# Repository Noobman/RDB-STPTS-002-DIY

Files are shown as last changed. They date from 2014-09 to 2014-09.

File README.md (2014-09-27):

RDB-STPTS-002-DIY
=================

3Dprint or CNC extension board for *any* development board (5v or 3.3v logic level)

Further info at www.reprap.org/wiki/RDB-STPTS-002-DIY

Current TODO list:

*rework the 6.3mm fuse footprint (currently does not fit correctly)

*maybe? add led indicators for endstops driven by low Vg(th) mosfet

*maybe? add current limited vcc for endstops headers just in case

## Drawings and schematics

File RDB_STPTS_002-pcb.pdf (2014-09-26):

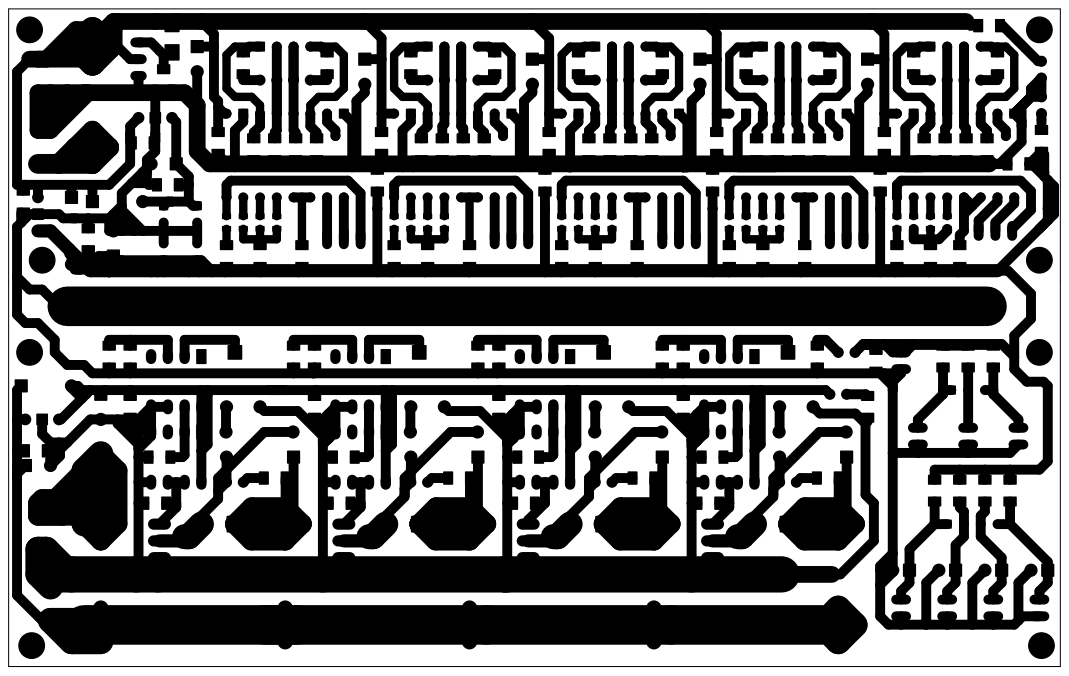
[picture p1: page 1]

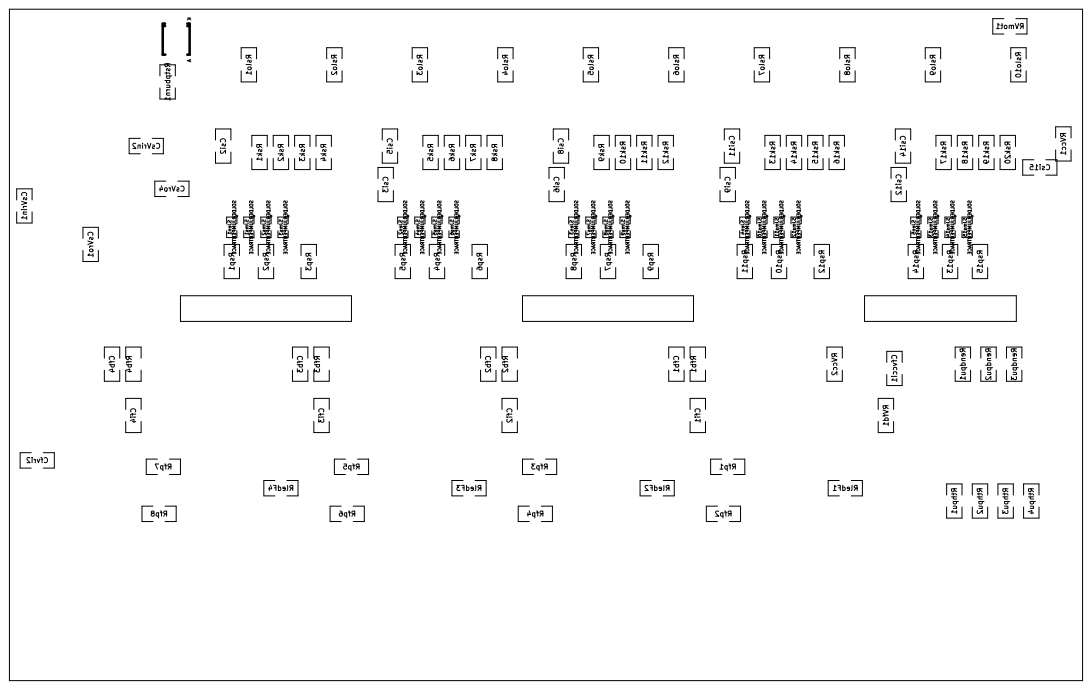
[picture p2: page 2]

SJen1 SOLDERJUMPERTRACE SJen2 SOLDERJUMPERTRACE SJen3 SOLDERJUMPERTRACE SJen4 SOLDERJUMPERTRACE SJen5 SOLDERJUMPERTRACE SJms1 SOLDERJUMPERTRACE SJms2 SOLDERJUMPERTRACE SJms3 SOLDERJUMPERTRACE SJms4 SOLDERJUMPERTRACE SJms5 SOLDERJUMPERTRACE SJms6 SOLDERJUMPERTRACE SJms7 SOLDERJUMPERTRACE SJms8 SOLDERJUMPERTRACE SJms9 SOLDERJUMPERTRACE SJms10 SOLDERJUMPERTRACE SJms11 SOLDERJUMPERTRACE SJms12 SOLDERJUMPERTRACE SJms13 SOLDERJUMPERTRACE SJms14 SOLDERJUMPERTRACE SJms15 SOLDERJUMPERTRACE RVcc1 RVmot1 CsVrin1 CsVro1 Cfi1 Csi2 Csi3 Csi5 Csi6 Csi8 Csi9 Csi11 Csi12 Csi14 Csi15 Rfp1 Rfp2 RledF1 Rsk1 Rsk2 Rsk3 Rsk4 Rsk5 Rsk6 Rsk7 Rsk8 Rsk9 Rsk10 Rsk11 Rsk12 Rsk13 Rsk14 Rsk15 Rsk16 Rsk17 Rsk18 Rsk19 Rsk20 Rslo1 Rslo2 Rslo3 Rslo4 Rslo5 Rslo6 Rslo7 Rslo8 Rslo9 Rslo10 Rsp1 Rsp2 Rsp3 Rsp5 Rsp4 Rsp6 Rsp8 Rsp7 Rsp9 Rsp10 Cfi2 Rfp3 Rfp4 RledF2 Cfi4 Cfi3 Rfp5 Rfp6 Rfp7 Rfp8 RledF4 RledF3 Cfvri2 Rfb4 Rfb3 Rfb2 Rfb1

# www.reprap.org/wiki/RDB - OSHW - GPLv3

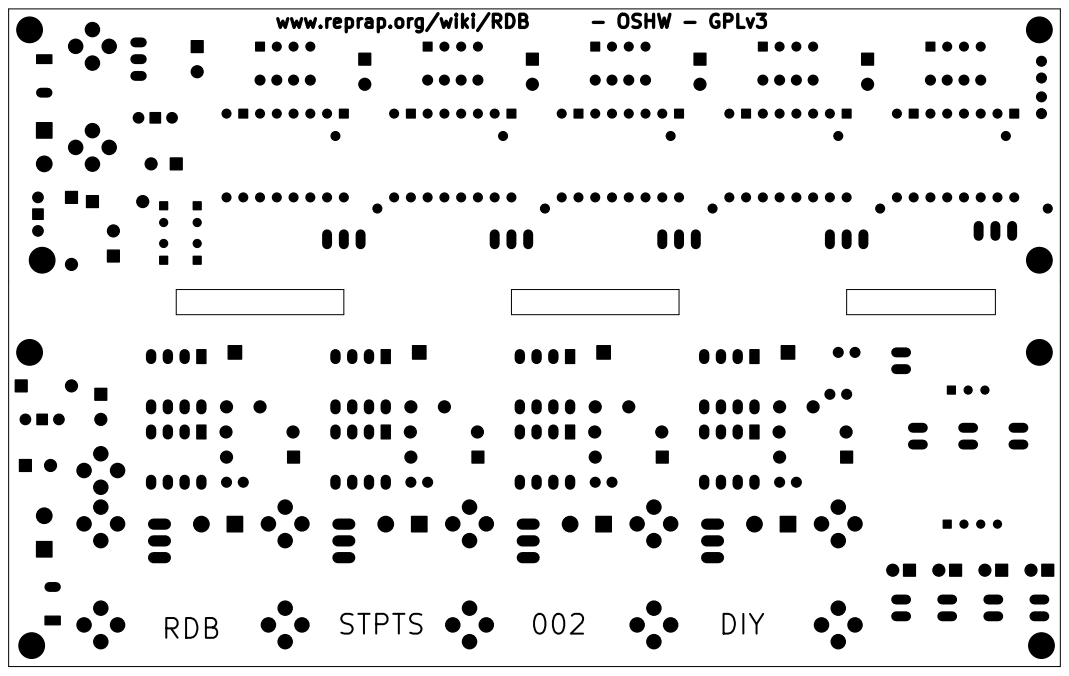
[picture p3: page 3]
RDB; STPTS; DIY

Pomot1 | Pomot2 | Pomot3 | Pomot4 | Pomot5 UP1 POLOLU_A4988 | UP2 POLOLU_A4988 | UP3 POLOLU_A4988 | UP4 POLOLU_A4988 | UP5 POLOLU_A4988 Rlim1 | Rlim2 | Rlim3 | Rlim4 | Rlim5 Hole1 Hole3 | Hole2 Hole4
Ledso1 BI_LED_2_PINS Ledso2 BI_LED_2_PINS | Ledso3 BI_LED_2_PINS Ledso4 BI_LED_2_PINS | Ledso5 BI_LED_2_PINS Ledso6 BI_LED_2_PINS | Ledso7 BI_LED_2_PINS Ledso8 BI_LED_2_PINS | Ledso9 BI_LED_2_PINS Ledso10 BI_LED_2_PINS Pc1 CONN_3 | Pc2 CONN_3 | Pc3 CONN_3 | Pc4 CONN_3 | Pc5 CONN_3 LedVcc1 | greenLedVmot1 green DFW1 FET_OUT1

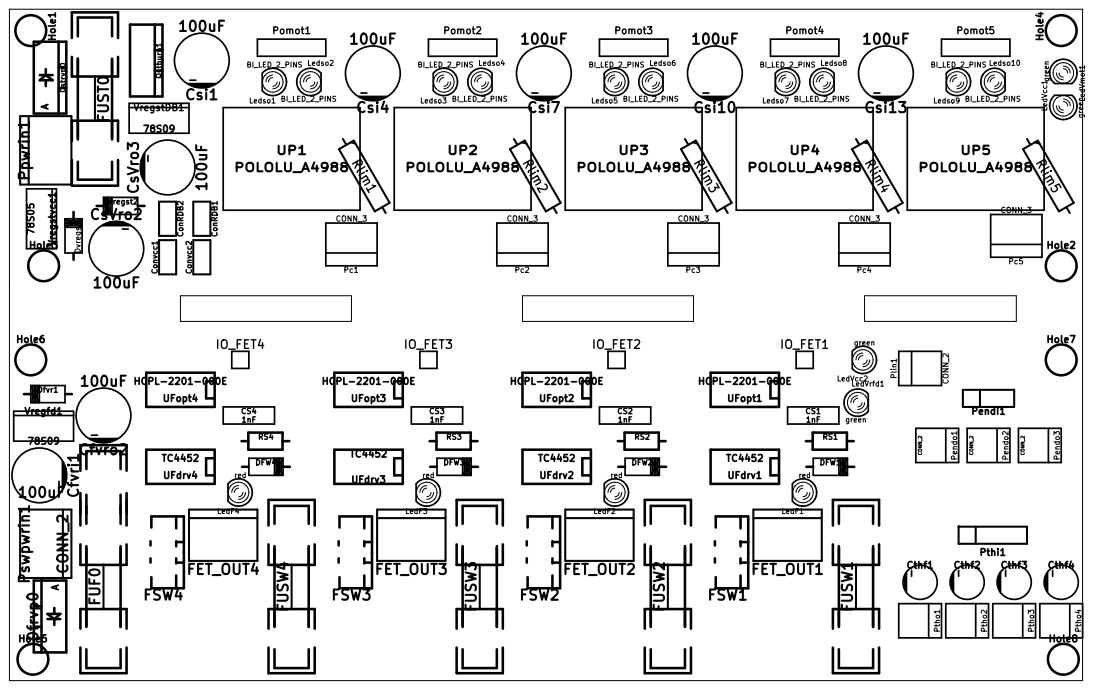
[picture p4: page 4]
FSW1; FUSW¹; LedF1 UFdrv1; red TC4452 DFW2 FET_OUT2; FSW2; FUSW²; LedF2; red Ppwrin1 Pswpwrin1; CONN_2; UFdrv2 TC4452 DFW4; DFW3 FET_OUT4; FET_OUT3; FSW4; FSW3 FUSW⁴; FUSW³; LedF3; red; LedF4; UFdrv3 TC4452 UFdrv4 TC4452 Dstrvp0 A; FUST0 Dfrvp0; Vregfd1; 78S09Vregstvcc1 78S⁰⁵; RS1 Hole5 Hole6; Hole7 Hole8 FUF0; ConRDB²; ConRDB¹ Convcc1; Convcc2 VregstDB1; 78S09 Dvregst2 Dvregst1; Qstburn1 Dfvr1; IO_FET4; IO_FET3; IO_FET2; IO_FET1; LedVrfd1 green; Pendo1 CONN_2; Pendo2 CONN_2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

UFopt1 HCPL-2201-000E UFopt2 HCPL-2201-000E UFopt3 HCPL-2201-000E UFopt4 HCPL-2201-000E

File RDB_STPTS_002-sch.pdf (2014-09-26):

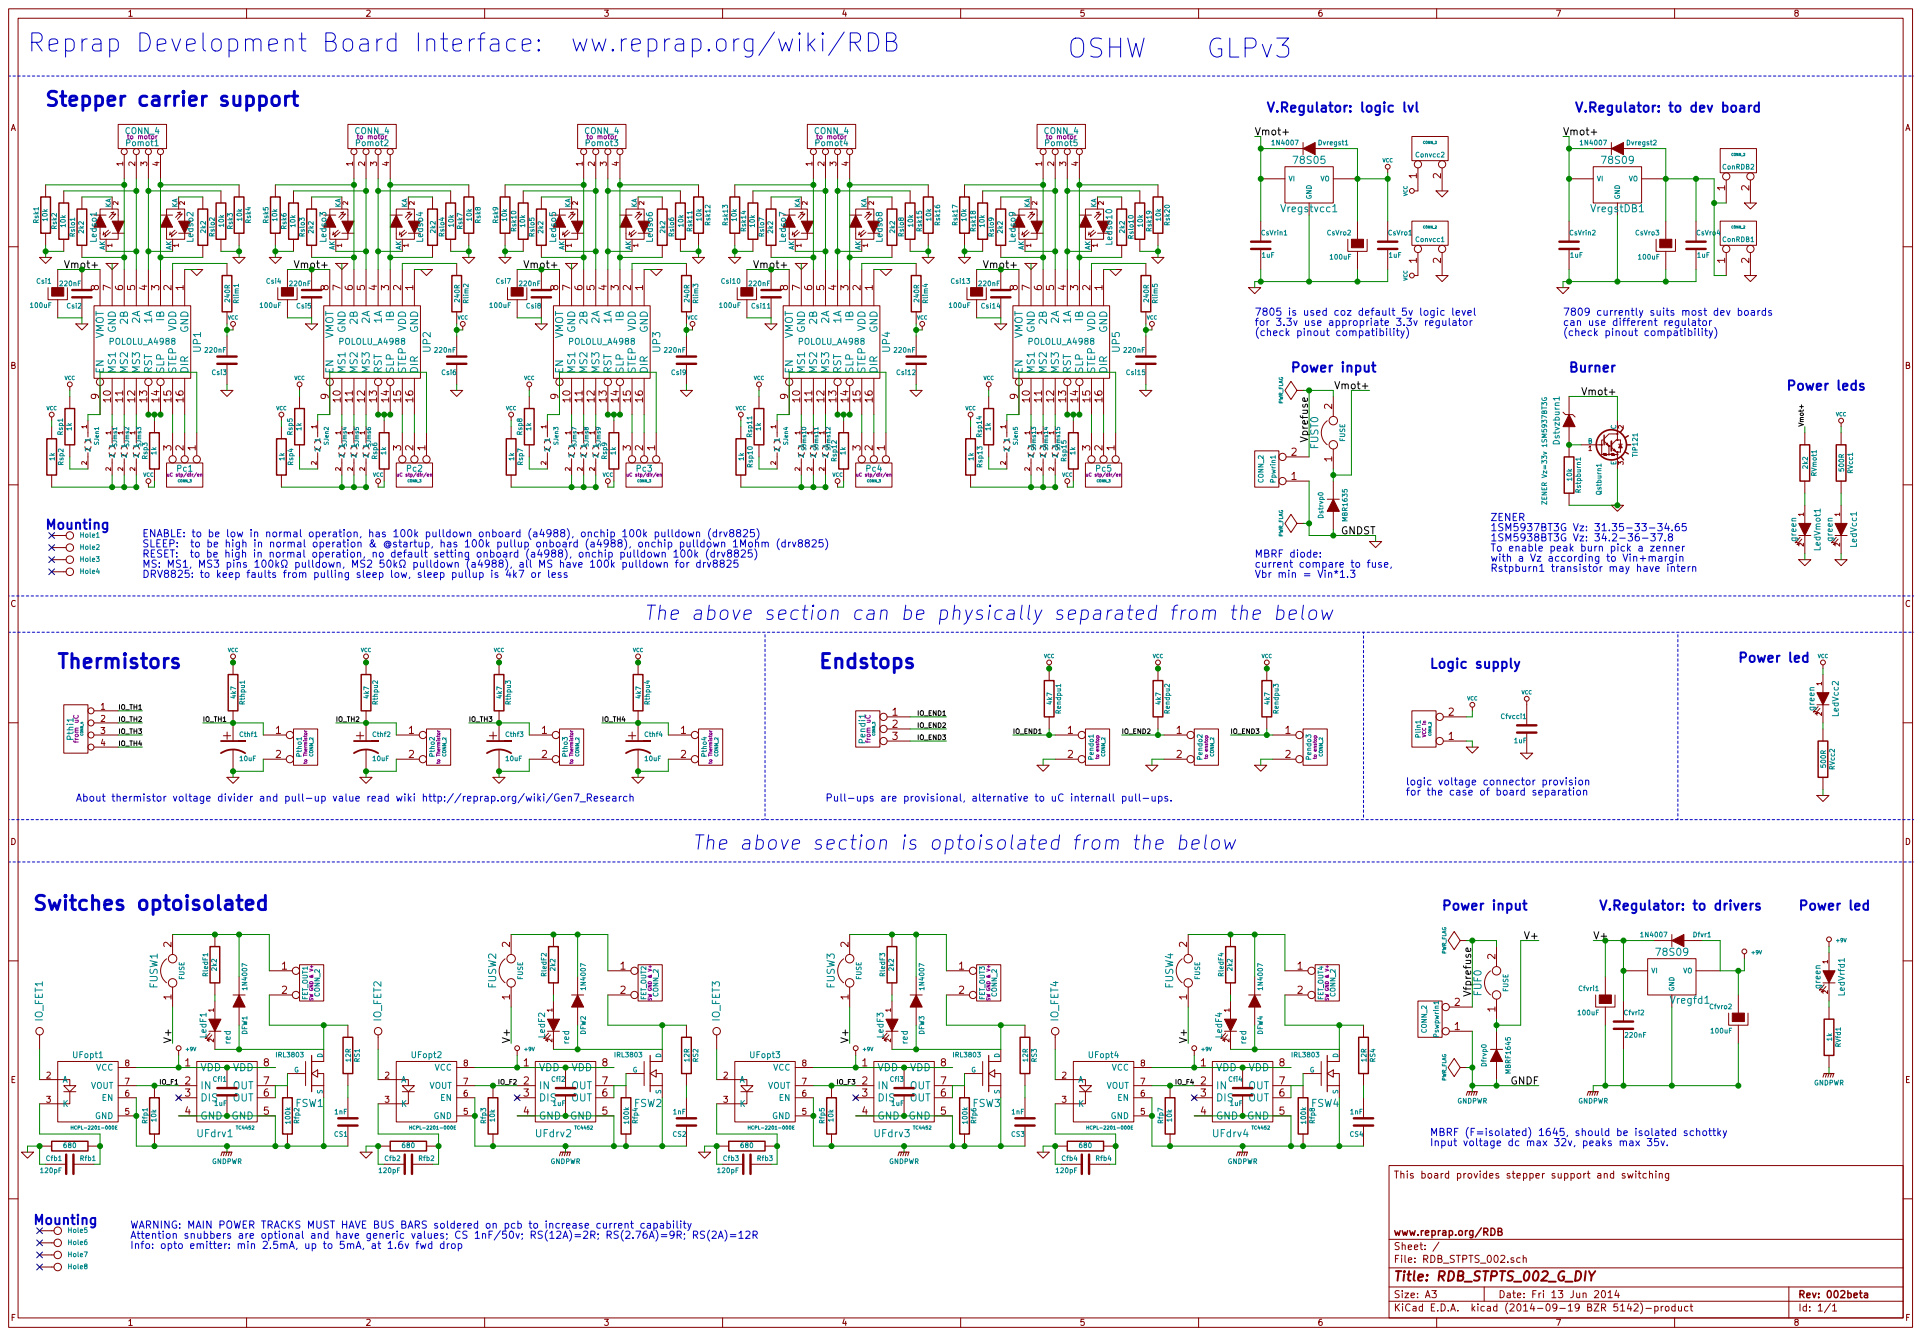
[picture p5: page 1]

CONN_2 V.Regulator: to dev board

1 VDD
(check pinout compatibility) MBRF diode: current compare to fuse, Vbr min = Vin*1.3 Vprefuse

VCC 7805 is used coz default 5v logic level
for 3.3v use appropriate 3.3v regulator

7809 currently suits most dev boards
can use different regulator
(check pinout compatibility)

9 MS1 10 MS2 11 MS3 12 RST 13 SLP 14 STEP 15 DIR 16 UP1POLOLU_A4988

9 MS1 10 MS2 11 MS3 12 RST 13 SLP 14 STEP 15 DIR 16 UP2POLOLU_A4988

9 MS1 10 MS2 11 MS3 12 RST 13 SLP 14 STEP 15 DIR 16 UP3POLOLU_A4988

9 MS1 10 MS2 11 MS3 12 RST 13 SLP 14 STEP 15 DIR 16 UP4POLOLU_A4988

9 MS1 10 MS2 11 MS3 12 RST 13 SLP 14 STEP 15 DIR 16 UP5POLOLU_A4988

3 Qstburn1 TIP121 Rstpburn1 10k Dstvzburn1 ZENER Vz=33v 1SM5937BT3G Vmot+ Burner ZENER

To enable peak burn pick a zenner
with a Vz according to Vin+margin
Rstpburn1 transistor may have intern

SLEEP: to be high in normal operation & @startup, has 100k pullup onboard (a4988), onchip pulldown 1Mohm (drv8825)
RESET: to be high in normal operation, no default setting onboard (a4988), onchip pulldown 100k (drv8825)
MS: MS1, MS3 pins 100k pulldown, MS2 50k pulldown (a4988), all MS have 100k pulldown for drv8825

The above section can be physically separated from the below

logic voltage connector provision
for the case of board separation

The above section is optoisolated from the below

HCPL-2201-000E Hole5 Hole6 Hole7 Hole8
Input voltage dc max 32v, peaks max 35v. Cfb1

MBRF (F=isolated) 1645, should be isolated schottky

This board provides stepper support and switching

WARNING: MAIN POWER TRACKS MUST HAVE BUS BARS soldered on pcb to increase current capability
Attention snubbers are optional and have generic values; CS 1nF/50v; RS(12A)=2R; RS(2.76A)=9R; RS(2A)=12R
Info: opto emitter: min 2.5mA, up to 5mA, at 1.6v fwd drop

File: RDB_STPTS_002.sch Sheet: / www.reprap.org/RDB

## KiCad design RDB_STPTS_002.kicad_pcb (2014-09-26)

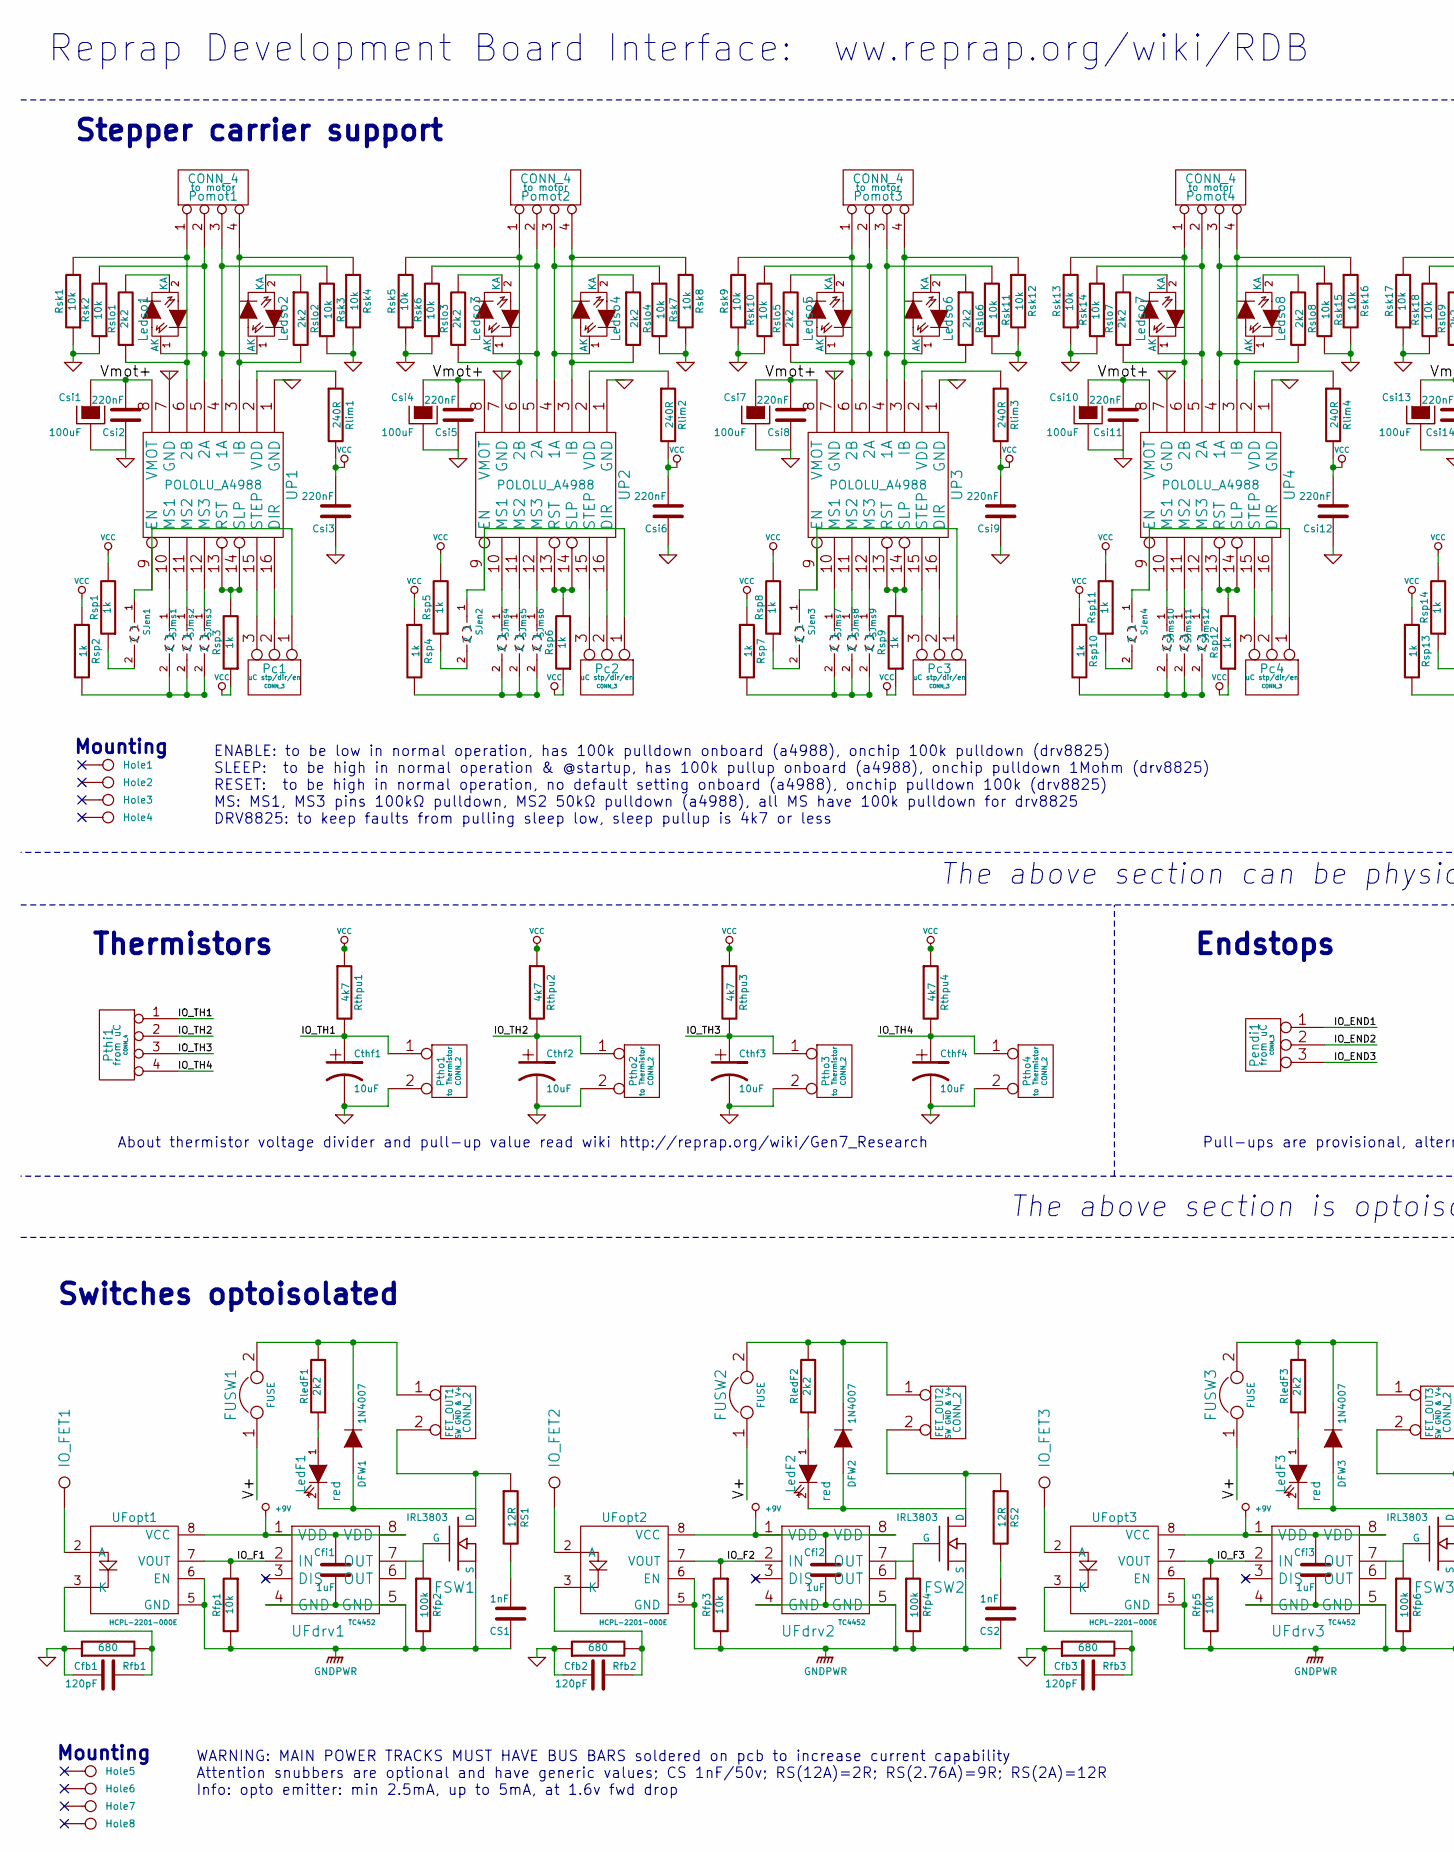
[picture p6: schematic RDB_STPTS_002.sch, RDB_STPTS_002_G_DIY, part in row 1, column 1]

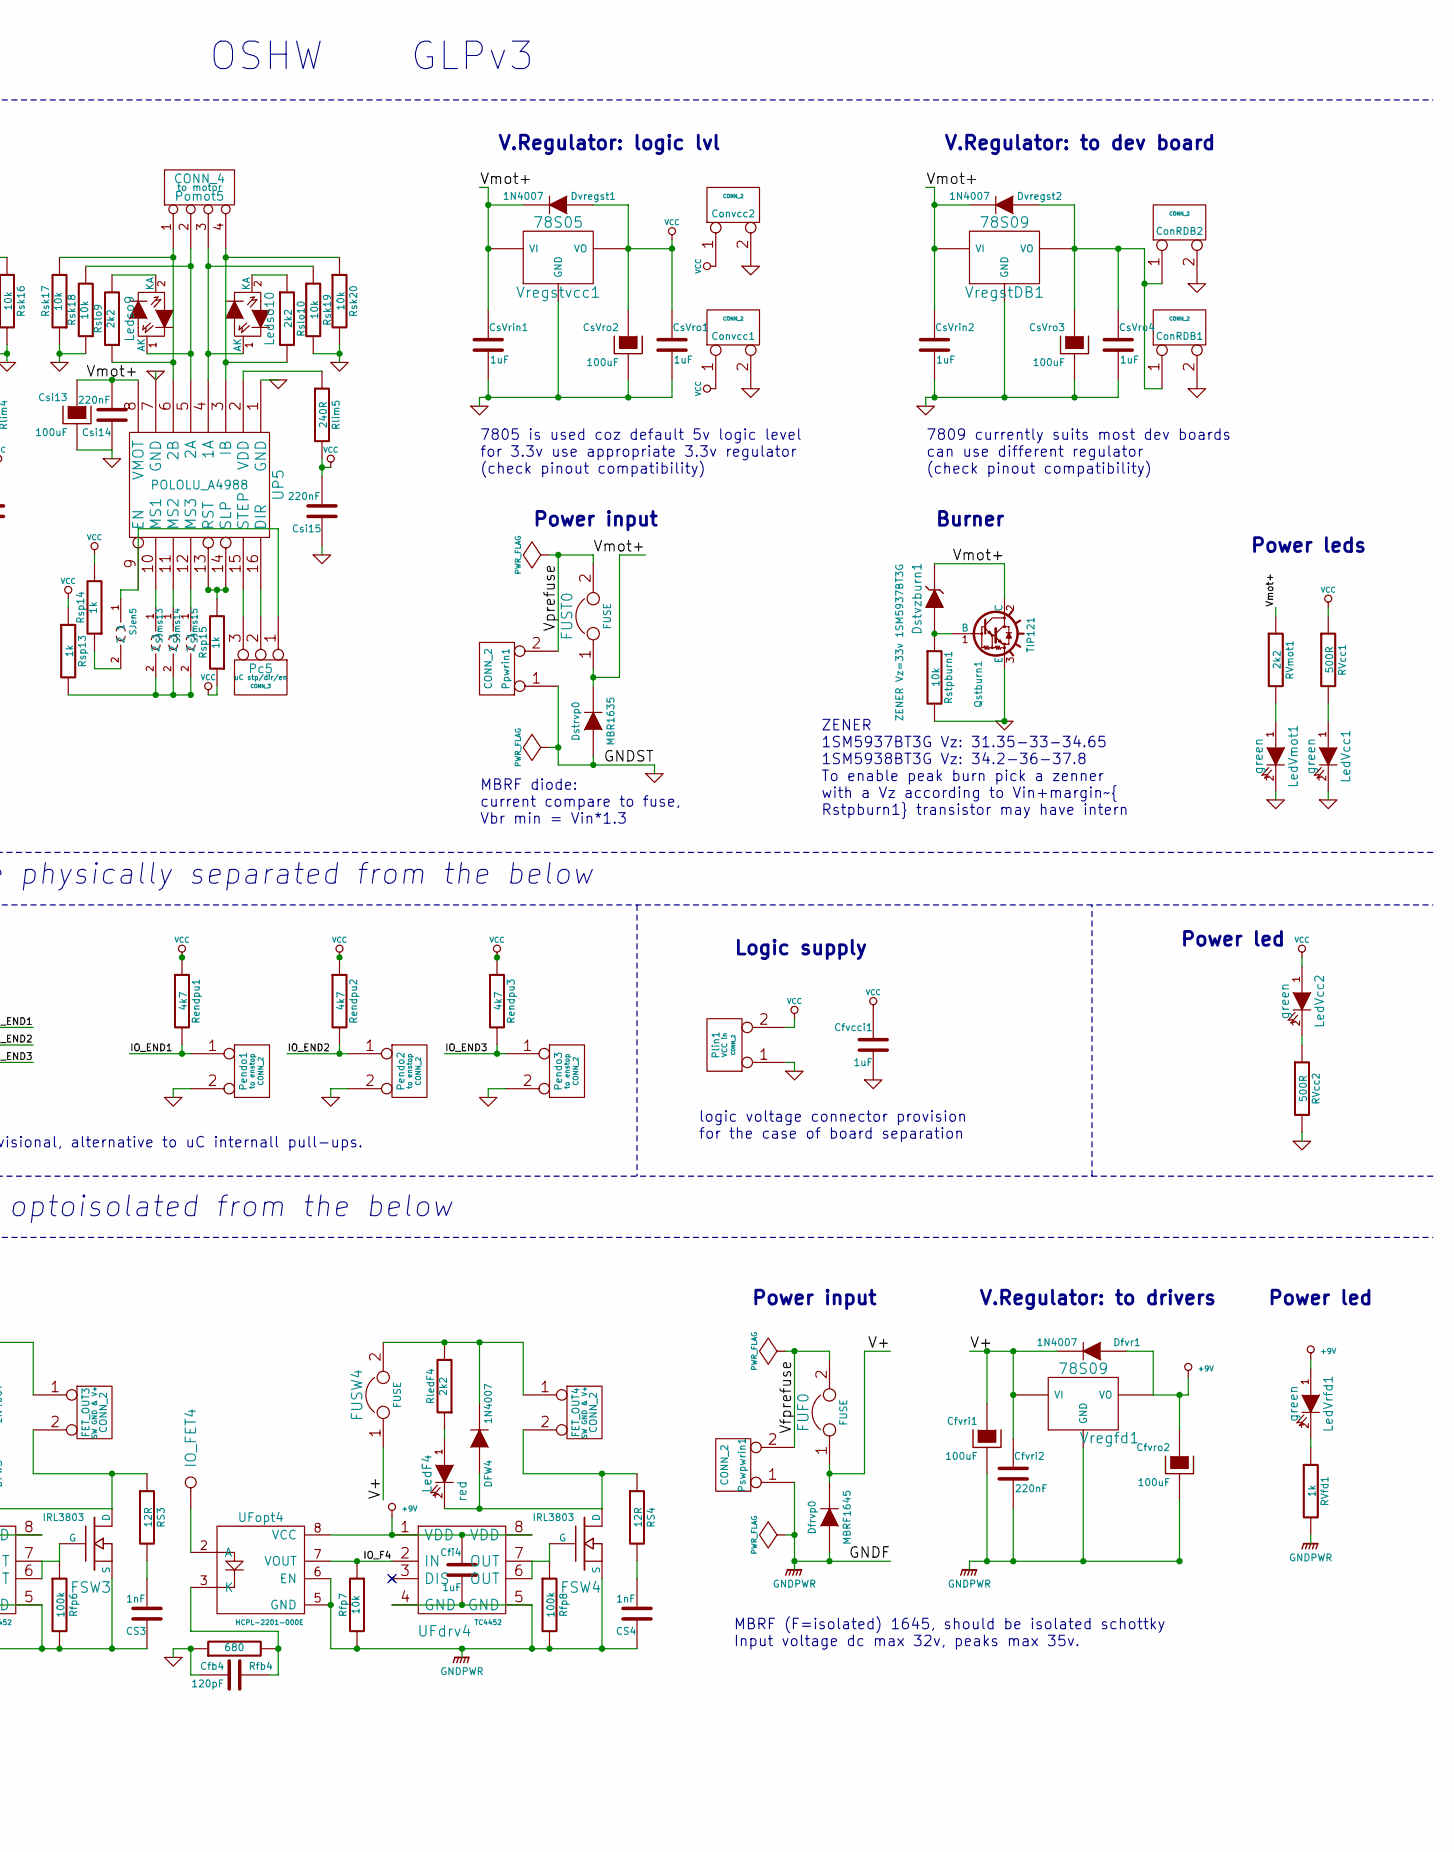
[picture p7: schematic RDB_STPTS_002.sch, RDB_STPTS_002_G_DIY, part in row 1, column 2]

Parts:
CS1, CS2, CS3, CS4: 1nF; Capacitor7x2RM5
Cfb1, Cfb2, Cfb3, Cfb4: 120pF; SMD-1206
Cfi1, Cfi2, Cfi3, Cfi4: 1uF; SM1206
Cfvcci1: 1uF; SM1206
Cfvri1: 100uF; Capacitor8x13RM3.8
Cfvri2: 220nF; SM1206
Cfvro2: 100uF; Capacitor8x13RM3.8
ConRDB1, ConRDB2: CONN_2; SIL-2
Convcc1, Convcc2: CONN_2; SIL-2
CsVrin1, CsVrin2: 1uF; SM1206
CsVro1, CsVro4: 1uF; SM1206
CsVro2, CsVro3: 100uF; Capacitor8x13RM3.8
Csi1, Csi4, Csi7, Csi10, Csi13: 100uF; Capacitor8x13RM3.8
Csi2, Csi3, Csi5, Csi6, Csi8, Csi9, Csi11, Csi12, Csi14, Csi15: 220nF; SM1206
Cthf1, Cthf2, Cthf3, Cthf4: 10uF; Capacitor5x6RM2.5
DFW1, DFW2, DFW3, DFW4: 1N4007; Diode_DO-41_SOD81_Horizontal_RM10
Dfrvp0: MBRF1645; Diode_TO-220_Vertical
Dfvr1: 1N4007; Diode_RM75
Dstrvp0: MBR1635; Diode_TO-220_Vertical
Dstvzburn1: ZENER Vz=33v 1SM5937BT3G; Diode-SMB_Standard
Dvregst1: 1N4007; Diode_DO-41_SOD81_Horizontal_RM10
Dvregst2: 1N4007; Diode_RM75
FET_OUT1, FET_OUT2, FET_OUT3, FET_OUT4: CONN_2; bornier2
FSW1, FSW2, FSW3, FSW4: IRL3803; TO-220_FET-GDS_Vertical_LargePads
FUF0: FUSE; Fuseholder5x20x32_horiz_open_universal_Type-III
FUST0: FUSE; Fuseholder5x20_horiz_open_universal_Type-III
FUSW1, FUSW2, FUSW3, FUSW4: FUSE; Fuseholder5x20_horiz_open_universal_Type-III
Hole1, Hole2, Hole3, Hole4, Hole5, Hole6, Hole7, Hole8: CONN_1; 1pin
IO_FET1, IO_FET2, IO_FET3, IO_FET4: CONN_1; Pin_Header_Straight_1x01
LedF1, LedF2, LedF3, LedF4: red; LED-3MM
LedVcc1, LedVcc2: green; LED-3MM
LedVmot1: green; LED-3MM
LedVrfd1: green; LED-3MM
Ledso1, Ledso2, Ledso3, Ledso4, Ledso5, Ledso6, Ledso7, Ledso8, Ledso9, Ledso10: BI_LED_2_PINS; LED-3MM
Pc1, Pc2, Pc3, Pc4, Pc5: CONN_3; PINHEAD1-3
Pendi1: CONN_3; SIL-3
Pendo1, Pendo2, Pendo3: CONN_2; PINHEAD1-2
Plin1: CONN_2; PINHEAD1-2
Pomot1, Pomot2, Pomot3, Pomot4, Pomot5: CONN_4; PIN_ARRAY_4x1
Ppwrin1: CONN_2; bornier2
Pswpwrin1: CONN_2; bornier2
Pthi1: CONN_4; SIL-4
Ptho1, Ptho2, Ptho3, Ptho4: CONN_2; PINHEAD1-2
Qstburn1: TIP121; TO-220_Neutral123_Vertical
RS1, RS2, RS3, RS4: 12R; Resistor_Horizontal_RM10mm
RVcc1, RVcc2: 500R; SM1206
RVfd1: 1k; SM1206
RVmot1: 2k2; SM1206
Rendpu1, Rendpu2, Rendpu3: 4k7; SM1206
Rfb1, Rfb2, Rfb3, Rfb4: 680; SM1206
Rfp1, Rfp3, Rfp5, Rfp7: 10k; SM1206
Rfp2, Rfp4, Rfp6, Rfp8: 100k; SM1206
RledF1, RledF2, RledF3, RledF4: 2k2; SM1206
Rlim1, Rlim2, Rlim3, Rlim4, Rlim5: 240R; R5
Rsk1, Rsk2, Rsk3, Rsk4, Rsk5, Rsk6, Rsk7, Rsk8, Rsk9, Rsk10, Rsk11, Rsk12, Rsk13, Rsk14, Rsk15, Rsk16, Rsk17, Rsk18, Rsk19, Rsk20: 10k; SM1206
Rslo1, Rslo2, Rslo3, Rslo4, Rslo5, Rslo6, Rslo7, Rslo8, Rslo9, Rslo10: 2k2; SM1206
Rsp1, Rsp2, Rsp3, Rsp4, Rsp5, Rsp6, Rsp7, Rsp8, Rsp9, Rsp10, Rsp11, Rsp12, Rsp13, Rsp14, Rsp15: 1k; SM1206
Rstpburn1: 10k; SM1206
Rthpu1, Rthpu2, Rthpu3, Rthpu4: 4k7; SM1206
SJen1, SJen2, SJen3, SJen4, SJen5: SOLDERJUMPERTRACE; SM0805
SJms1, SJms2, SJms3, SJms4, SJms5, SJms6, SJms7, SJms8, SJms9, SJms10, SJms11, SJms12, SJms13, SJms14, SJms15: SOLDERJUMPERTRACE; SM0805
UFdrv1, UFdrv2, UFdrv3, UFdrv4: TC4452; DIP-8__300_ELL
UFopt1, UFopt2, UFopt3, UFopt4: HCPL-2201-000E; DIP-8__300_ELL
UP1, UP2, UP3, UP4, UP5: POLOLU_A4988; SWDIP8_.6W.pololu
Vregfd1: 78S09; LM78XXV
VregstDB1: 78S09; LM78XXV
Vregstvcc1: 78S05; LM78XXV

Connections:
+9V: Cfi1.1, Cfi2.1, Cfi3.1, Cfi4.1, Cfvro2.1, Dfvr1.1 (A), LedVrfd1.1 (A), UFdrv1.1 (VDD), UFdrv1.8 (VDD), UFdrv2.1 (VDD), UFdrv2.8 (VDD), UFdrv3.1 (VDD), UFdrv3.8 (VDD), UFdrv4.1 (VDD), UFdrv4.8 (VDD), UFopt1.8 (VCC), UFopt2.8 (VCC), UFopt3.8 (VCC), UFopt4.8 (VCC), Vregfd1.VO
/IO_END1: Pendi1.1, Pendo1.1, Rendpu1.2
/IO_END2: Pendi1.2 (PM), Pendo2.1, Rendpu2.2
/IO_END3: Pendi1.3, Pendo3.1, Rendpu3.2
/IO_F1: Rfp1.1, UFdrv1.2 (IN), UFopt1.7 (VOUT)
/IO_F2: Rfp3.1, UFdrv2.2 (IN), UFopt2.7 (VOUT)
/IO_F3: Rfp5.1, UFdrv3.2 (IN), UFopt3.7 (VOUT)
/IO_F4: Rfp7.1, UFdrv4.2 (IN), UFopt4.7 (VOUT)
/IO_TH1: Cthf1.1, Pthi1.1, Ptho1.1, Rthpu1.2
/IO_TH2: Cthf2.1, Pthi1.2, Ptho2.1, Rthpu2.2
/IO_TH3: Cthf3.1, Pthi1.3, Ptho3.1, Rthpu3.2
/IO_TH4: Cthf4.1, Pthi1.4, Ptho4.1, Rthpu4.2
/V+: Cfvri1.1, Cfvri2.1, Dfrvp0.2 (K), Dfvr1.2 (K), FUF0.1, FUSW1.1, FUSW2.1, FUSW3.1, FUSW4.1, Vregfd1.VI
/Vfprefuse: FUF0.2, Pswpwrin1.2 (PM)
/Vmot+: CsVrin1.1, CsVrin2.1, Csi1.1, Csi2.2, Csi4.1, Csi5.2, Csi7.1, Csi8.2, Csi10.1, Csi11.2, Csi13.1, Csi14.2, Dstrvp0.2 (K), Dstvzburn1.2 (K), Dvregst1.2 (K), Dvregst2.2 (K), FUST0.1, Qstburn1.2 (C), RVmot1.1, UP1.8 (VMOT), UP2.8 (VMOT), UP3.8 (VMOT), UP4.8 (VMOT), UP5.8 (VMOT), VregstDB1.VI, Vregstvcc1.VI
/Vprefuse: FUST0.2, Ppwrin1.2 (PM)
GND: Cfb1.2, Cfb2.2, Cfb3.2, Cfb4.2, Cfvcci1.2, ConRDB1.2 (PM), ConRDB2.2 (PM), Convcc1.2 (PM), Convcc2.2 (PM), CsVrin1.2, CsVrin2.2, CsVro1.2, CsVro2.2, CsVro3.2, CsVro4.2, Csi1.2, Csi2.1, Csi3.1, Csi4.2, Csi5.1, Csi6.1, Csi7.2, Csi8.1, Csi9.1, Csi10.2, Csi11.1, Csi12.1, Csi13.2, Csi14.1, Csi15.1, Cthf1.2, Cthf2.2, Cthf3.2, Cthf4.2, Dstrvp0.1 (A), LedVcc1.2 (K), LedVmot1.2 (K), Pendo1.2 (PM), Pendo2.2 (PM), Pendo3.2 (PM), Plin1.1, Ppwrin1.1, Ptho1.2 (PM), Ptho2.2 (PM), Ptho3.2 (PM), Ptho4.2 (PM), Qstburn1.3 (E), RVcc2.2, Rfb1.1, Rfb2.1, Rfb3.1, Rfb4.1, Rsk1.1, Rsk2.1, Rsk3.2, Rsk4.2, Rsk5.1, Rsk6.1, Rsk7.2, Rsk8.2, Rsk9.1, Rsk10.1, Rsk11.2, Rsk12.2, Rsk13.1, Rsk14.1, Rsk15.2, Rsk16.2, Rsk17.1, Rsk18.1, Rsk19.2, Rsk20.2, Rstpburn1.2, UP1.1 (GND), UP1.7 (GND), UP2.1 (GND), UP2.7 (GND), UP3.1 (GND), UP3.7 (GND), UP4.1 (GND), UP4.7 (GND), UP5.1 (GND), UP5.7 (GND), VregstDB1.GND, Vregstvcc1.GND
GNDPWR: CS1.1, CS2.1, CS3.1, CS4.1, Cfi1.2, Cfi2.2, Cfi3.2, Cfi4.2, Cfvri1.2, Cfvri2.2, Cfvro2.2, Dfrvp0.1 (A), FSW1.S, FSW2.S, FSW3.S, FSW4.S, Pswpwrin1.1, RVfd1.2, Rfp1.2, Rfp2.2, Rfp3.2, Rfp4.2, Rfp5.2, Rfp6.2, Rfp7.2, Rfp8.2, UFdrv1.4 (GND), UFdrv1.5 (GND), UFdrv2.4 (GND), UFdrv2.5 (GND), UFdrv3.4 (GND), UFdrv3.5 (GND), UFdrv4.4 (GND), UFdrv4.5 (GND), UFopt1.5 (GND), UFopt1.6 (EN), UFopt2.5 (GND), UFopt2.6 (EN), UFopt3.5 (GND), UFopt3.6 (EN), UFopt4.5 (GND), UFopt4.6 (EN), Vregfd1.GND
unnamed: CS1.2, RS1.2
unnamed: CS2.2, RS2.2
unnamed: CS3.2, RS3.2
unnamed: CS4.2, RS4.2
unnamed: Cfb1.1, Rfb1.2, UFopt1.3 (K)
unnamed: Cfb2.1, Rfb2.2, UFopt2.3 (K)
unnamed: Cfb3.1, Rfb3.2, UFopt3.3 (K)
unnamed: Cfb4.1, Rfb4.2, UFopt4.3 (K)
unnamed: ConRDB1.1, ConRDB2.1, CsVro3.1, CsVro4.1, Dvregst2.1 (A), VregstDB1.VO
unnamed: DFW1.1 (A), FET_OUT1.2 (PM), FSW1.D, LedF1.2 (K), RS1.1
unnamed: DFW1.2 (K), FET_OUT1.1, FUSW1.2, RledF1.2
unnamed: DFW2.1 (A), FET_OUT2.2 (PM), FSW2.D, LedF2.2 (K), RS2.1
unnamed: DFW2.2 (K), FET_OUT2.1, FUSW2.2, RledF2.2
unnamed: DFW3.1 (A), FET_OUT3.2 (PM), FSW3.D, LedF3.2 (K), RS3.1
unnamed: DFW3.2 (K), FET_OUT3.1, FUSW3.2, RledF3.2
unnamed: DFW4.1 (A), FET_OUT4.2 (PM), FSW4.D, LedF4.2 (K), RS4.1
unnamed: DFW4.2 (K), FET_OUT4.1, FUSW4.2, RledF4.2
unnamed: Dstvzburn1.1 (A), Qstburn1.1 (B), Rstpburn1.1
unnamed: FSW1.G, Rfp2.1, UFdrv1.6 (OUT), UFdrv1.7 (OUT)
unnamed: FSW2.G, Rfp4.1, UFdrv2.6 (OUT), UFdrv2.7 (OUT)
unnamed: FSW3.G, Rfp6.1, UFdrv3.6 (OUT), UFdrv3.7 (OUT)
unnamed: FSW4.G, Rfp8.1, UFdrv4.6 (OUT), UFdrv4.7 (OUT)
unnamed: IO_FET1.1, UFopt1.2 (A)
unnamed: IO_FET2.1, UFopt2.2 (A)
unnamed: IO_FET3.1, UFopt3.2 (A)
unnamed: IO_FET4.1, UFopt4.2 (A)
unnamed: LedF1.1 (A), RledF1.1
unnamed: LedF2.1 (A), RledF2.1
unnamed: LedF3.1 (A), RledF3.1
unnamed: LedF4.1 (A), RledF4.1
unnamed: LedVcc1.1 (A), RVcc1.2
unnamed: LedVcc2.2 (K), RVcc2.1
unnamed: LedVmot1.1 (A), RVmot1.2
unnamed: LedVrfd1.2 (K), RVfd1.1
unnamed: Ledso1.1 (AK), Pomot1.2, Rsk2.2, UP1.5 (2A)
unnamed: Ledso1.2 (KA), Rslo1.2
unnamed: Ledso2.1 (AK), Pomot1.3, Rsk3.1, UP1.4 (1A)
unnamed: Ledso2.2 (KA), Rslo2.1
unnamed: Ledso3.1 (AK), Pomot2.2, Rsk6.2, UP2.5 (2A)
unnamed: Ledso3.2 (KA), Rslo3.2
unnamed: Ledso4.1 (AK), Pomot2.3, Rsk7.1, UP2.4 (1A)
unnamed: Ledso4.2 (KA), Rslo4.1
unnamed: Ledso5.1 (AK), Pomot3.2, Rsk10.2, UP3.5 (2A)
unnamed: Ledso5.2 (KA), Rslo5.2
unnamed: Ledso6.1 (AK), Pomot3.3, Rsk11.1, UP3.4 (1A)
unnamed: Ledso6.2 (KA), Rslo6.1
unnamed: Ledso7.1 (AK), Pomot4.2, Rsk14.2, UP4.5 (2A)
unnamed: Ledso7.2 (KA), Rslo7.2
unnamed: Ledso8.1 (AK), Pomot4.3, Rsk15.1, UP4.4 (1A)
unnamed: Ledso8.2 (KA), Rslo8.1
unnamed: Ledso9.1 (AK), Pomot5.2, Rsk18.2, UP5.5 (2A)
unnamed: Ledso9.2 (KA), Rslo9.2
unnamed: Ledso10.1 (AK), Pomot5.3, Rsk19.1, UP5.4 (1A)
unnamed: Ledso10.2 (KA), Rslo10.1
unnamed: Pc1.1, SJen1.1, UP1.9 (EN)
unnamed: Pc1.2 (PM), UP1.16 (DIR)
unnamed: Pc1.3, UP1.15 (STEP)
unnamed: Pc2.1, SJen2.1, UP2.9 (EN)
unnamed: Pc2.2 (PM), UP2.16 (DIR)
unnamed: Pc2.3, UP2.15 (STEP)
unnamed: Pc3.1, SJen3.1, UP3.9 (EN)
unnamed: Pc3.2 (PM), UP3.16 (DIR)
unnamed: Pc3.3, UP3.15 (STEP)
unnamed: Pc4.1, SJen4.1, UP4.9 (EN)
unnamed: Pc4.2 (PM), UP4.16 (DIR)
unnamed: Pc4.3, UP4.15 (STEP)
unnamed: Pc5.1, SJen5.1, UP5.9 (EN)
unnamed: Pc5.2 (PM), UP5.16 (DIR)
unnamed: Pc5.3, UP5.15 (STEP)
unnamed: Pomot1.1, Rsk1.2, Rslo1.1, UP1.6 (2B)
unnamed: Pomot1.4, Rsk4.1, Rslo2.2, UP1.3 (IB)
unnamed: Pomot2.1, Rsk5.2, Rslo3.1, UP2.6 (2B)
unnamed: Pomot2.4, Rsk8.1, Rslo4.2, UP2.3 (IB)
unnamed: Pomot3.1, Rsk9.2, Rslo5.1, UP3.6 (2B)
unnamed: Pomot3.4, Rsk12.1, Rslo6.2, UP3.3 (IB)
unnamed: Pomot4.1, Rsk13.2, Rslo7.1, UP4.6 (2B)
unnamed: Pomot4.4, Rsk16.1, Rslo8.2, UP4.3 (IB)
unnamed: Pomot5.1, Rsk17.2, Rslo9.1, UP5.6 (2B)
unnamed: Pomot5.4, Rsk20.1, Rslo10.2, UP5.3 (IB)
unnamed: Rlim1.1, UP1.2 (VDD)
unnamed: Rlim2.1, UP2.2 (VDD)
unnamed: Rlim3.1, UP3.2 (VDD)
unnamed: Rlim4.1, UP4.2 (VDD)
unnamed: Rlim5.1, UP5.2 (VDD)
unnamed: Rsp1.1, SJen1.2
unnamed: Rsp2.2, SJms1.2, SJms2.2, SJms3.2
unnamed: Rsp3.2, UP1.13 (RST), UP1.14 (SLP)
unnamed: Rsp4.2, SJms4.2, SJms5.2, SJms6.2
unnamed: Rsp5.1, SJen2.2
unnamed: Rsp6.2, UP2.13 (RST), UP2.14 (SLP)
unnamed: Rsp7.2, SJms7.2, SJms8.2, SJms9.2
unnamed: Rsp8.1, SJen3.2
unnamed: Rsp9.2, UP3.13 (RST), UP3.14 (SLP)
unnamed: Rsp10.2, SJms10.2, SJms11.2, SJms12.2
unnamed: Rsp11.1, SJen4.2
unnamed: Rsp12.2, UP4.13 (RST), UP4.14 (SLP)
unnamed: Rsp13.2, SJms13.2, SJms14.2, SJms15.2
unnamed: Rsp14.1, SJen5.2
unnamed: Rsp15.2, UP5.13 (RST), UP5.14 (SLP)
unnamed: SJms1.1, UP1.10 (MS1)
unnamed: SJms2.1, UP1.11 (MS2)
unnamed: SJms3.1, UP1.12 (MS3)
unnamed: SJms4.1, UP2.10 (MS1)
unnamed: SJms5.1, UP2.11 (MS2)
unnamed: SJms6.1, UP2.12 (MS3)
unnamed: SJms7.1, UP3.10 (MS1)
unnamed: SJms8.1, UP3.11 (MS2)
unnamed: SJms9.1, UP3.12 (MS3)
unnamed: SJms10.1, UP4.10 (MS1)
unnamed: SJms11.1, UP4.11 (MS2)
unnamed: SJms12.1, UP4.12 (MS3)
unnamed: SJms13.1, UP5.10 (MS1)
unnamed: SJms14.1, UP5.11 (MS2)
unnamed: SJms15.1, UP5.12 (MS3)
VCC: Cfvcci1.1, Convcc1.1, Convcc2.1, CsVro1.1, CsVro2.1, Csi3.2, Csi6.2, Csi9.2, Csi12.2, Csi15.2, Dvregst1.1 (A), LedVcc2.1 (A), Plin1.2 (PM), RVcc1.1, Rendpu1.1, Rendpu2.1, Rendpu3.1, Rlim1.2, Rlim2.2, Rlim3.2, Rlim4.2, Rlim5.2, Rsp1.2, Rsp2.1, Rsp3.1, Rsp4.1, Rsp5.2, Rsp6.1, Rsp7.1, Rsp8.2, Rsp9.1, Rsp10.1, Rsp11.2, Rsp12.1, Rsp13.1, Rsp14.2, Rsp15.1, Rthpu1.1, Rthpu2.1, Rthpu3.1, Rthpu4.1, Vregstvcc1.VO

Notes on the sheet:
Reprap Development Board Interface: ww.reprap.org/wiki/RDB
GLPv3
Power input
V.Regulator: logic lvl
Power leds
7805 is used coz default 5v logic level for 3.3v use appropriate 3.3v regulator (check pinout compatibility)
MBRF diode: current compare to fuse, Vbr min = Vin*1.3
OSHW
Mounting
ENABLE: to be low in normal operation, has 100k pulldown onboard (a4988), onchip 100k pulldown (drv8825) SLEEP: to be high in normal operation & @startup, has 100k pullup onboard (a4988), onchip pulldown 1Mohm (drv8825) RESET: to be high in normal operation, no default setting onboard (a4988), onch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
WARNING: MAIN POWER TRACKS MUST HAVE BUS BARS soldered on pcb to increase current capability Attention snubbers are optional and have generic values; CS 1nF/50v; RS(12A)=2R; RS(2.76A)=9R; RS(2A)=12R Info: opto emitter: min 2.5mA, up to 5mA, at 1.6v fwd drop
V.Regulator: to dev board
Burner
ZENER 1SM5937BT3G Vz: 31.35-33-34.65 1SM5938BT3G Vz: 34.2-36-37.8 To enable peak burn pick a zenner with a Vz according to Vin+margin~ Rstpburn1 transistor may have intern
Thermistors
Endstops
V.Regulator: to drivers
Switches optoisolated
The above section is optoisolated from the below
Stepper carrier support
The above section can be physically separated from the below
Logic supply
Power led
About thermistor voltage divider and pull-up value read wiki http://reprap.org/wiki/Gen7_Research
Pull-ups are provisional, alternative to uC internall pull-ups.
MBRF (F=isolated) 1645, should be isolated schottky Input voltage dc max 32v, peaks max 35v.
7809 currently suits most dev boards can use different regulator (check pinout compatibility)
logic voltage connector provision for the case of board separation

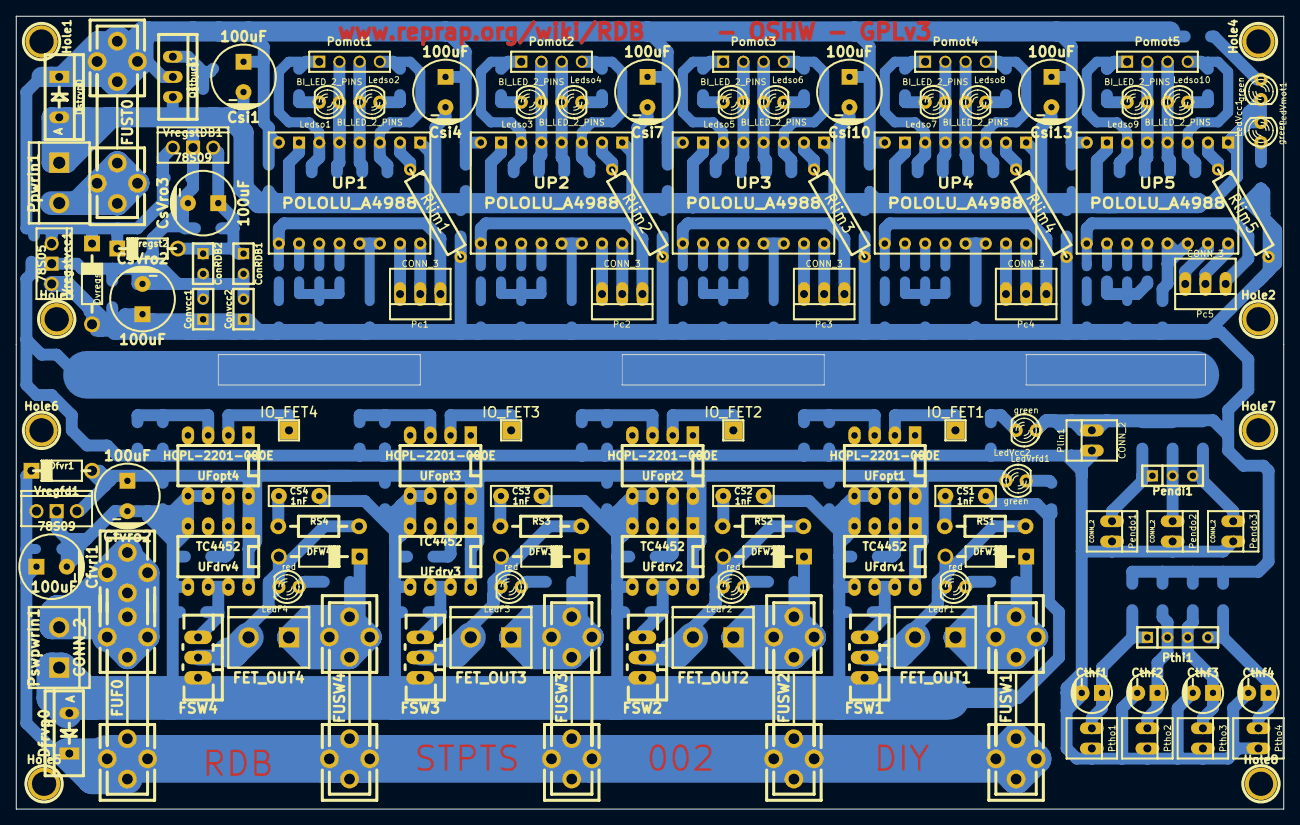
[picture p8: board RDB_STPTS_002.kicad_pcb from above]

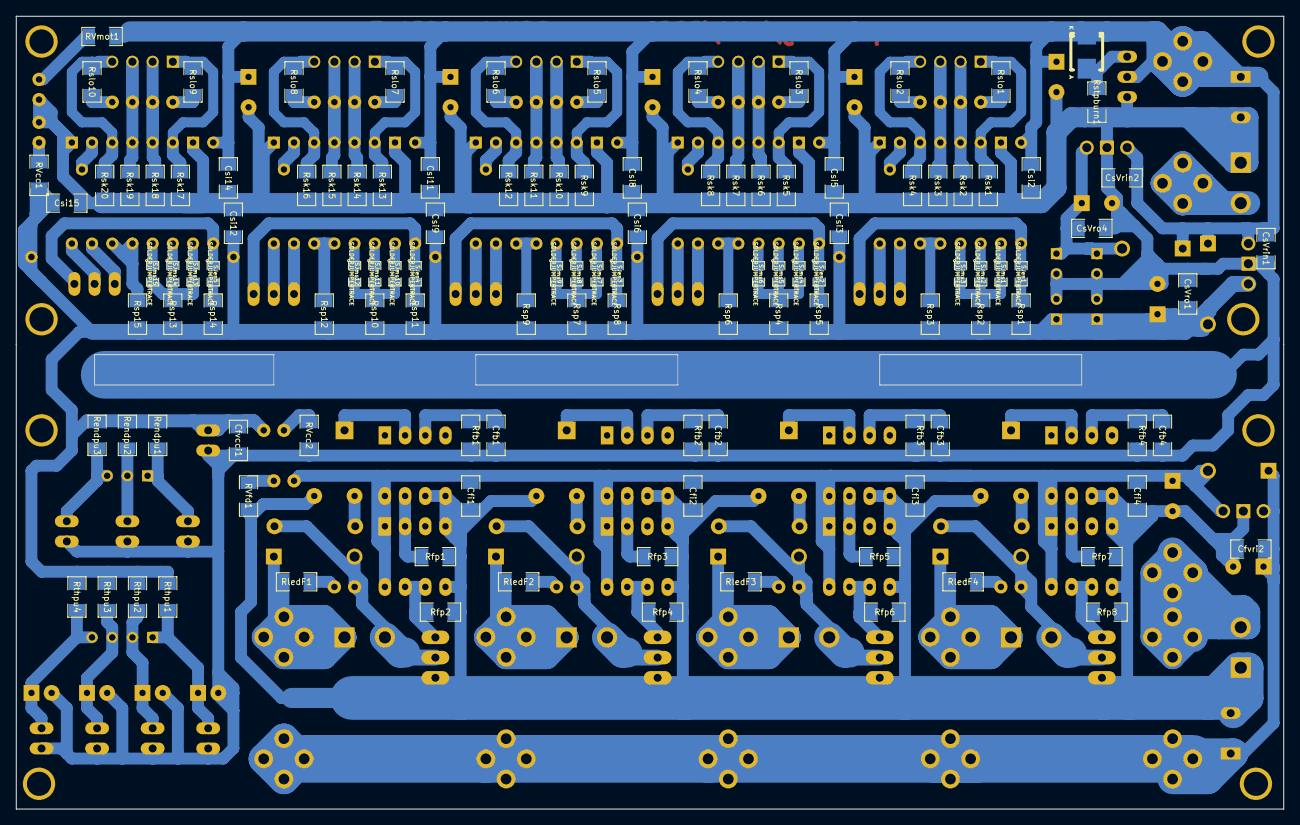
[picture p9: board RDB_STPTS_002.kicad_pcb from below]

Board: 2 copper layers, 159.4 x 99.7 mm, 240 parts (118 on the bottom side), 133 nets.
